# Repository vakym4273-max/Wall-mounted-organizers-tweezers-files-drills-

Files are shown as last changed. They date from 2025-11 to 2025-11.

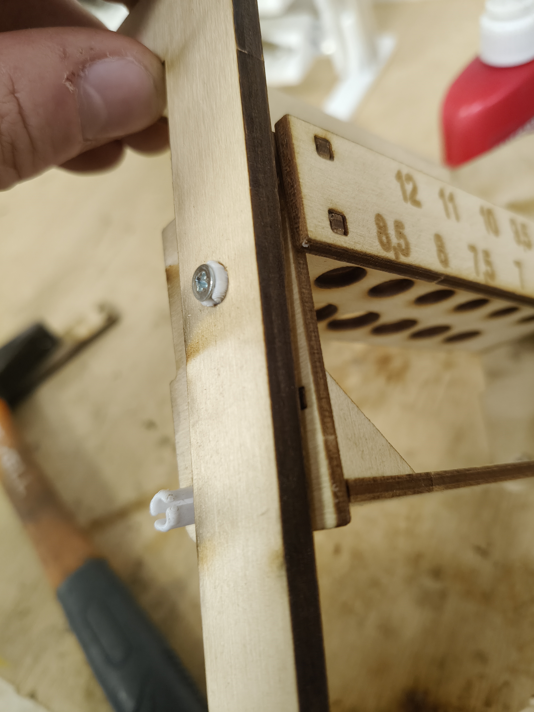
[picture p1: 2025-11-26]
Media/Photos/IMG20251120163726.jpg

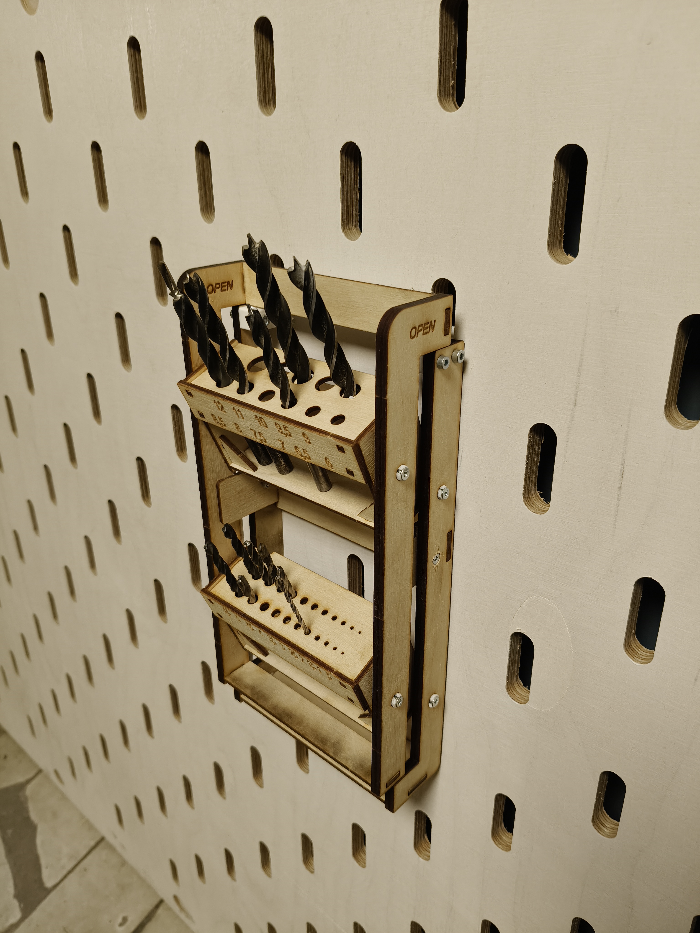
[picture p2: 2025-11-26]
Media/Photos/IMG20251120174527.jpg

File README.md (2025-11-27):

# 🛠️ Набор органайзеров для FabLab: свёрла, пинцеты, надфили

*Поворотно-выдвижной механизм для удобного доступа к инструментам*



[]()

## 🎯 О проекте

Набор из трёх настенных органайзеров, разработанных в рамках учебной практики "Практика цифрового производства" (FabLab). Особенность — инновационный поворотно-выдвижной механизм для органайзера свёрел.

### ✨ Особенности

**Органайзер для свёрел:**
- 🔄 **Поворотно-выдвижной механизм** — при раздвижении боковых стенок свёрла поворачиваются на 23° для удобного доступа
- 🎯 **Плотная фиксация** — каждый инструмент в отдельной ячейке  
- 🏗️ **Усиленная конструкция** — направляющие и винтовые соединения против люфта

**Органайзеры для пинцетов и надфилей:**
- 📏 **Эргономичное расположение** — быстрый доступ к часто используемым инструментам
- 🎪 **Компактность** — оптимальное использование пространства стены

## 🎥 Демонстрация

Работа механизма свёрел

## 📁 Структура проекта
**📁 CAD/**

│ ├── SolidWorks/ # Исходные файлы .SLDPRT, .SLDASM

│ └── STEP/ # Сборки в формате STEP

**📁 Production/**

│ ├── 3D_Print/ # STL и gcode файлы для 3D-печати

│ └── Laser_Cut/ # DXF файлы для лазерной резки

**📁 Documentation/**

│ ├── Технологический процесс сборки# Инструкция по сборке

**📁 Media/**

│ ├── Photos/ # Фотографии процесса и результата

│ ├── Videos/ # Видео сборки и работы

│ └── Gifs/ # Анимированные демонстрации

## 🛠 Технологии и материалы

### Оборудование
- **3D-принтер:** Prusa
- **Лазерный станок:** GCC Laser Pro
- **CAD:** SolidWorks

### Материалы
- **Фанера:** 3мм и 6мм (пазы рассчитаны на 2.85мм для плотной посадки)
- **PLA пластик** для 3D-печати
- **Крепёж:** Винты для усиления соединений
- **Клей:** ПВА для финальной фиксации

## 📋 Инструкция по сборке

### Подготовка деталей
1. **Лазерная резка:** Используйте файлы из папки `Laser_Cut/`
2. **3D-печать:** Напечатайте детали из папки `3D_Print/`
   - ⚠️ *Для мелких штифтов используйте высокое качество печати*

### Сборка органайзера свёрел
1. Соберите две внутрение секции из фанерных деталей
2. Соберите половину внешней рамы
3. Установите внутрение секции
4. Закройте второй половиной внешней части
5. Добавьте направляющие для уменьшения люфта, и винты по отверстиям штифтов
6. Проверьте работу механизма

### Монтаж на стену
1. Установите 3D-печатные крепления в пазы стены
2. Опустите органайзер для фиксации
3. Для надёжности можно зафиксировать клеем ПВА

## 🔧 Доработки и улучшения

В процессе тестирования были внесены следующие улучшения:
- ✅ **Направляющие** — добавлены для уменьшения люфта в механизме
- ✅ **Корректировка пазов** — размер уменьшен до 2.85мм для плотной посадки
- ✅ **Винтовое усиление** — штифты усилены винтами для прочности

## 👤 Автор

**Егор Смирнов** 
- Проект выполнен в рамках практики "Практика цифрового производства"
- Группа МТМО-25-3

---

*Проект разработан для лаборатории FabLab с целью оптимизации рабочего пространства*

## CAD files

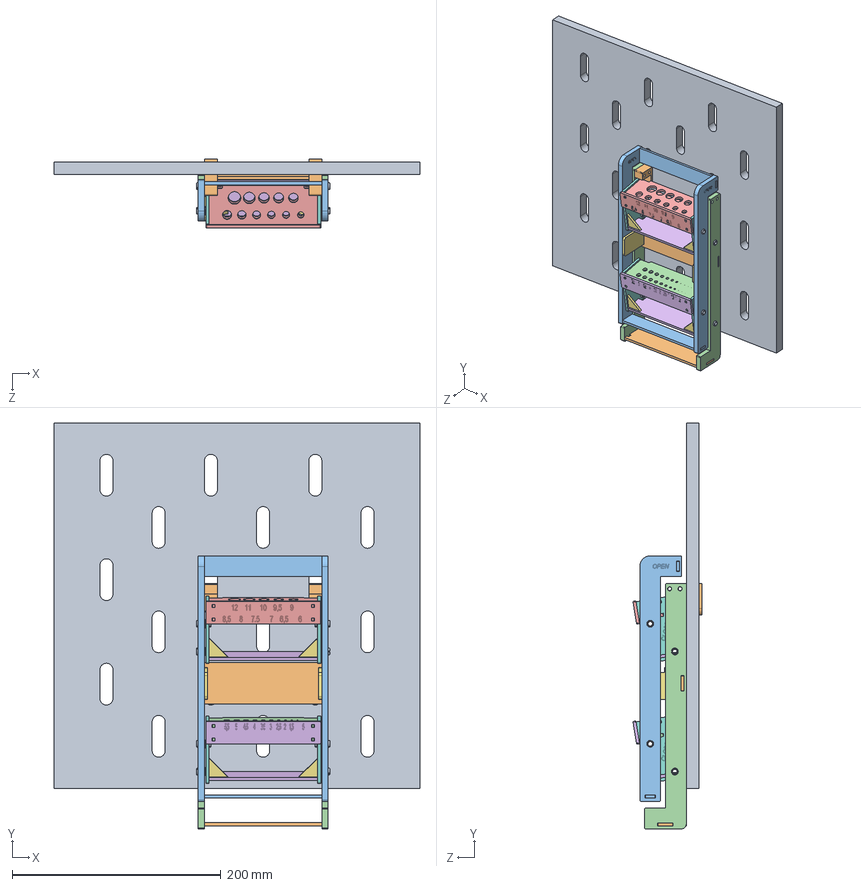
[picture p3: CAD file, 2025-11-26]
CAD/SolidWorks/Свёрла органайзер/0 Органайзер свёрла.SLDASM
350.0 x 388.8 x 66.3 mm
1 Стенка
2 Кронштейн свёрла x 2
4 Стенка подвижная свёрла x 2
3 Стенка основа свёрла x 2
7 Полка ячейки верхняя x 2
6 Полка ячейки нижняя x 2
10 Уголок свёрла x 4
5 Стенка ячейки x 4
9 штифт x 8
11 низ x 2
12 верх x 2
7.1 Полка ячейки верхняя x 2
13.1 маркировка свёрла верх
13.2 маркировка свёрла низ
14 направляюшая x 2

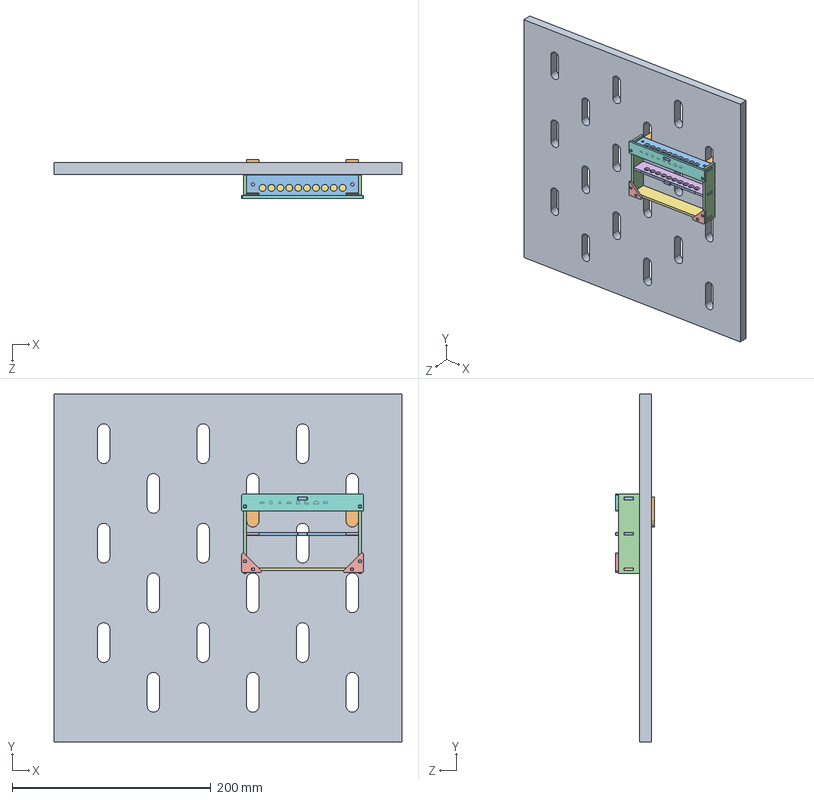
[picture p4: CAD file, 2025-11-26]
CAD/SolidWorks/Надфили органайзер/0 Органайзер надфили.SLDASM
350.0 x 350.0 x 39.5 mm
1 Стенка
2 Кронштейн надфили x 2
3 Полка верхняя надфили x 2
4 Стенка надфиди x 2
7 уголок x 2
5 Полка средняя надфили
6 Полка нижняя надфили
8 Маркировка

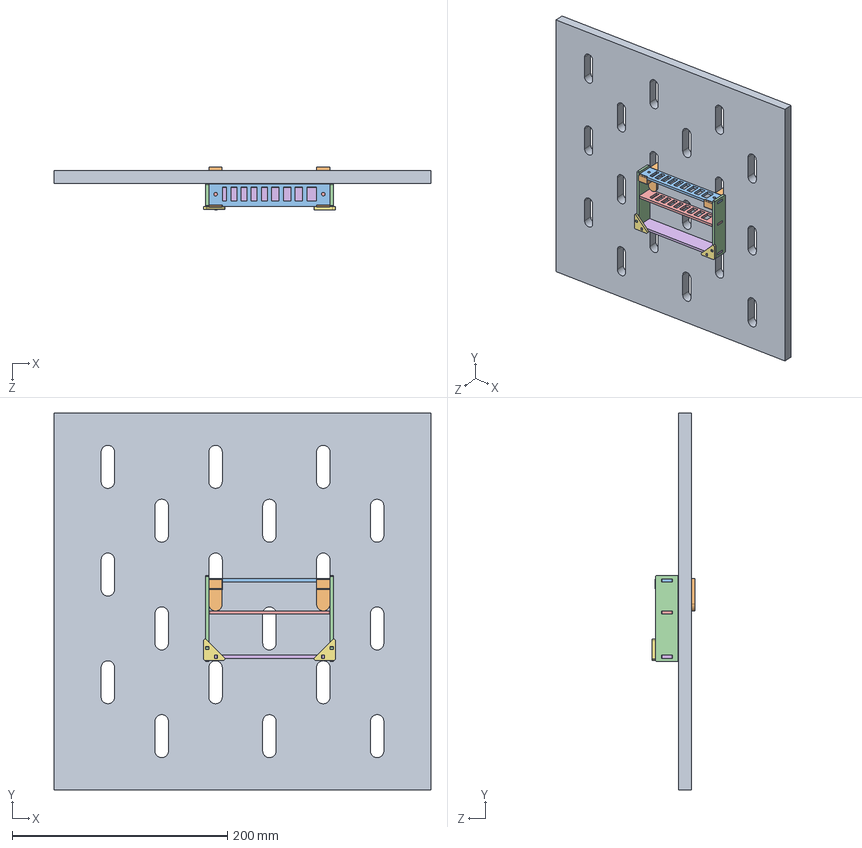
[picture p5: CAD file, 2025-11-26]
CAD/SolidWorks/Пинцеты органайзер/0 Органайзер пинцеты.SLDASM
350.0 x 350.0 x 39.8 mm
1 Стенка
2 Кронштейн Пинцеты x 2
3 Полка верхняя Пинцеты
4 Стенка пинцеты x 2
5 Полка средняя пинцеты
6 Полка нижняя пинцеты
7 уголок x 2

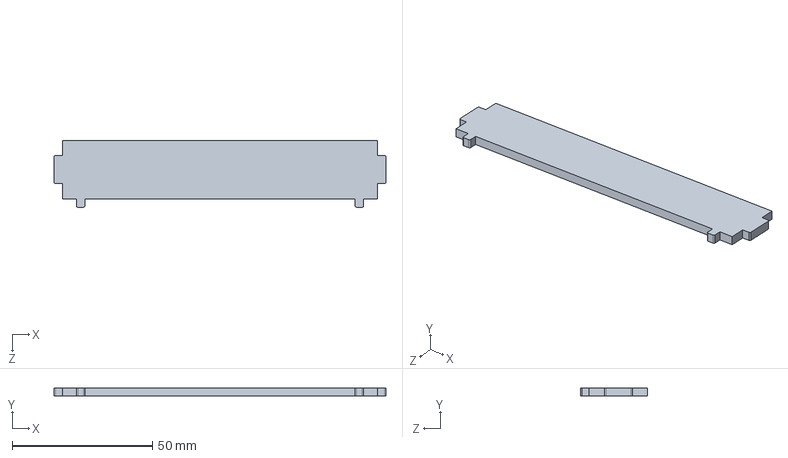
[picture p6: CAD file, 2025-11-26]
CAD/SolidWorks/Надфили органайзер/6 Полка нижняя надфили.SLDPRT
118.5 x 3.00 x 23.8 mm

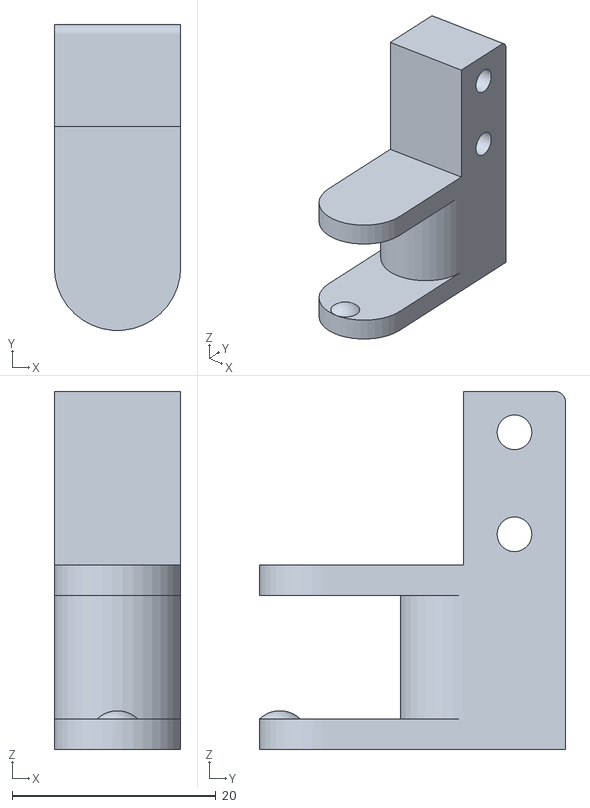
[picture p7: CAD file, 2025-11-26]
Production/3D_Print/2 Кронштейн свёрла.STL
12.4 x 30.0 x 35.1

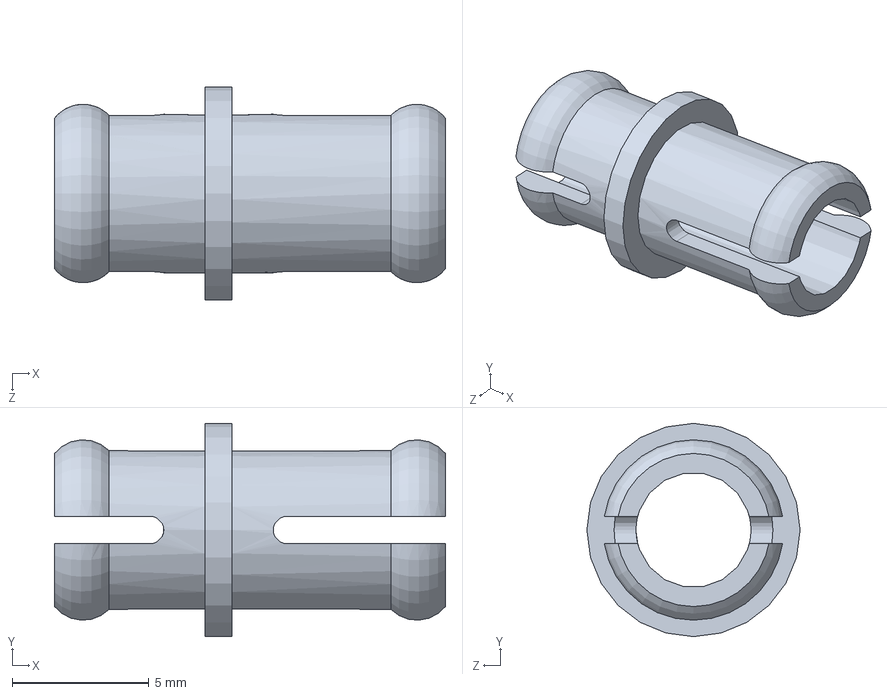
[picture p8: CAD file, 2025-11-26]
CAD/SolidWorks/Свёрла органайзер/9 штифт.SLDPRT
14.3 x 7.80 x 7.80 mm

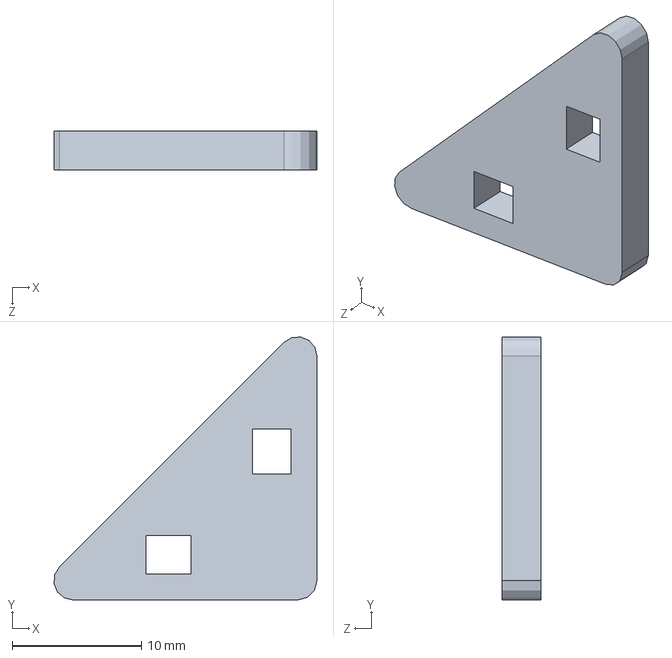
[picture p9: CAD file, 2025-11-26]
CAD/SolidWorks/Надфили органайзер/7 уголок.SLDPRT
20.4 x 20.4 x 3.00 mm

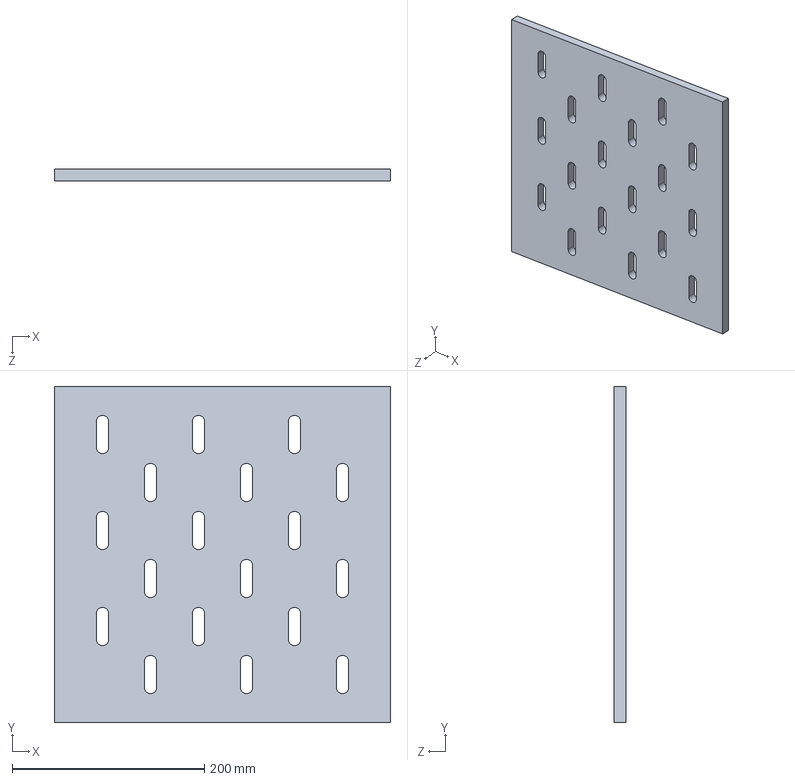
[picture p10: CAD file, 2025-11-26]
CAD/SolidWorks/Пинцеты органайзер/1 Стенка.SLDPRT
350.0 x 350.0 x 12.0 mm

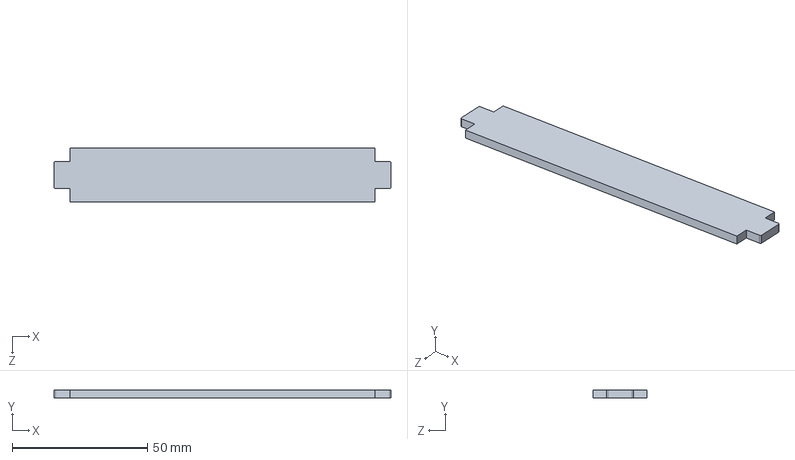
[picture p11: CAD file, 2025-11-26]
CAD/SolidWorks/Свёрла органайзер/12 верх.SLDPRT
124.5 x 3.00 x 20.0 mm

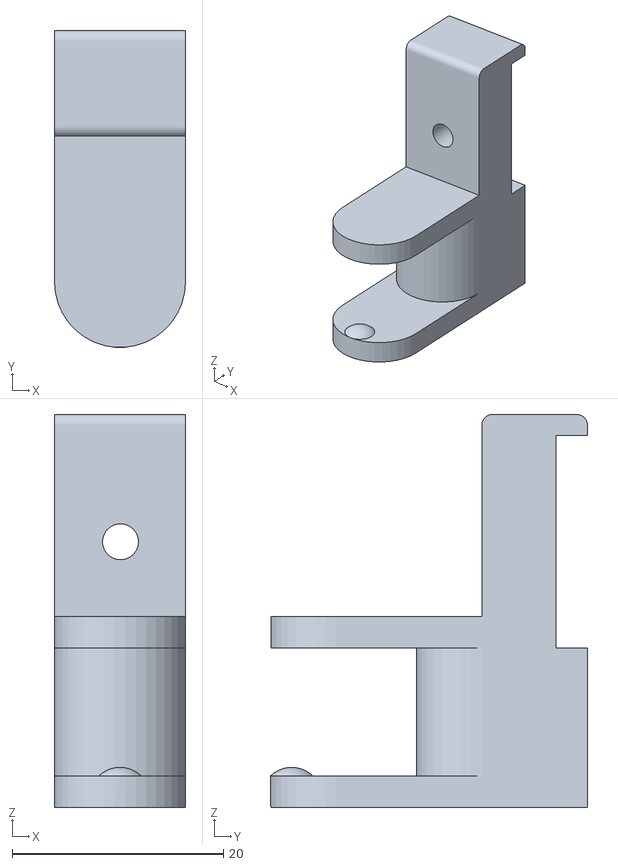
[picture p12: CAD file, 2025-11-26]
Production/3D_Print/2 Кронштейн Пинцеты.STL
12.4 x 30.0 x 37.2

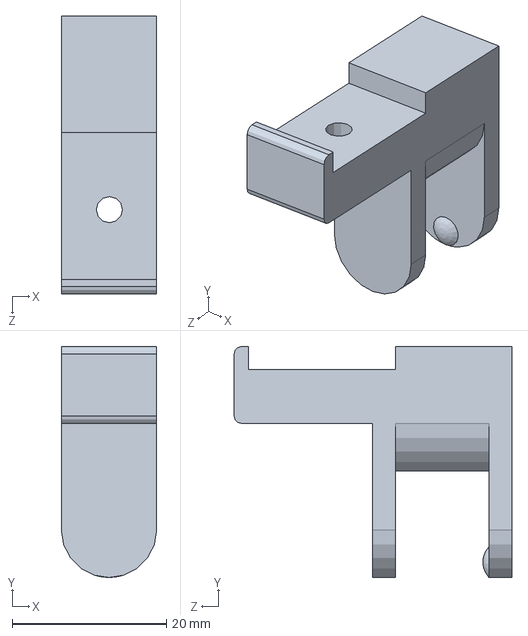
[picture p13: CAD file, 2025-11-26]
CAD/SolidWorks/Надфили органайзер/2 Кронштейн надфили.SLDPRT
12.4 x 30.0 x 36.1 mm

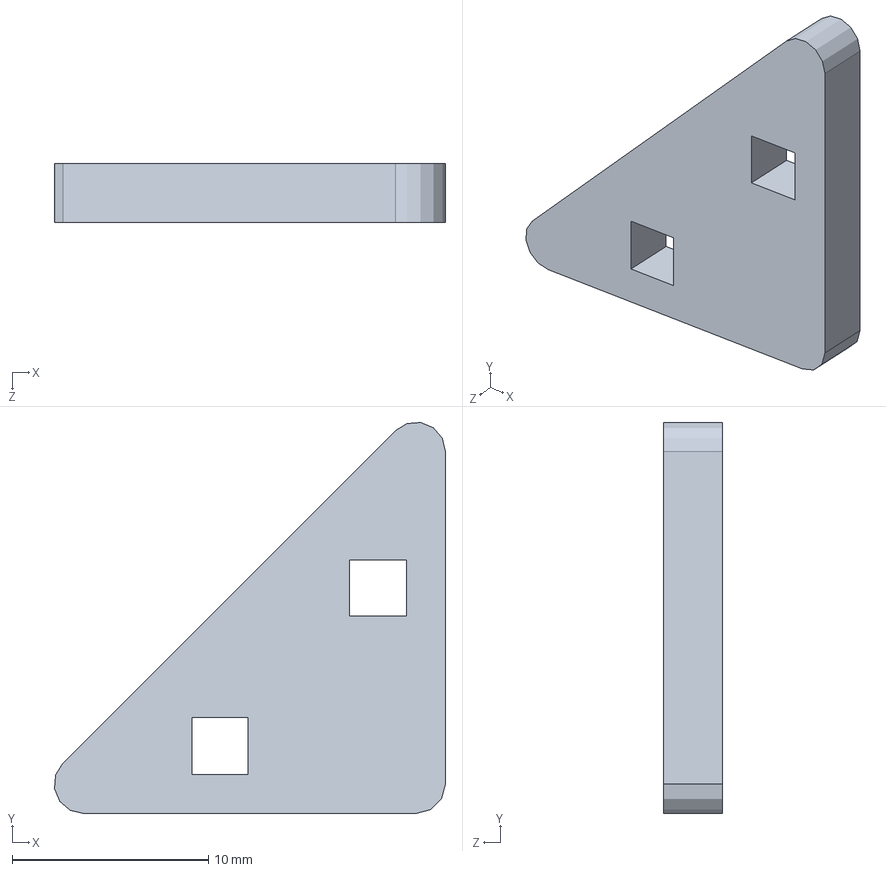
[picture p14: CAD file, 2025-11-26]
CAD/SolidWorks/Пинцеты органайзер/7 уголок.SLDPRT
19.9 x 19.9 x 3.00 mm

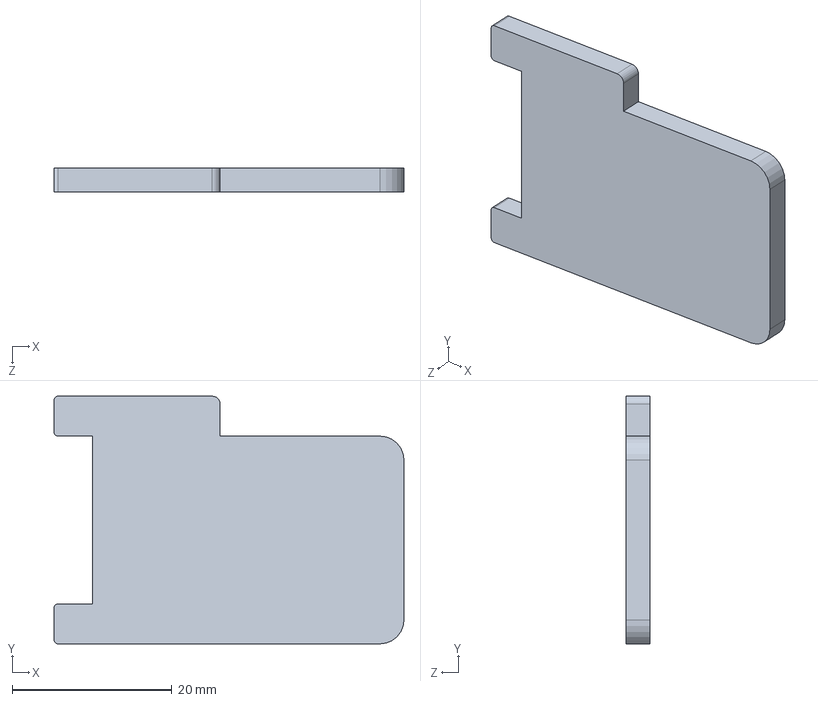
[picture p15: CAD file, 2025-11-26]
CAD/SolidWorks/Свёрла органайзер/14 направляюшая.SLDPRT
43.8 x 31.0 x 3.00 mm

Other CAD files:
CAD/SolidWorks/Пинцеты органайзер/6 Полка нижняя пинцеты.SLDPRT
CAD/STEP/0 Органайзер надфили.STEP
CAD/STEP/0 Органайзер пинцеты.STEP
Production/3D_Print/9 штифт.STL
Production/3D_Print/2 Кронштейн надфили.STL
CAD/SolidWorks/Надфили органайзер/1 Стенка.STEP
CAD/SolidWorks/Надфили органайзер/3 Полка верхняя надфили.SLDPRT
CAD/SolidWorks/Надфили органайзер/4 Стенка надфиди.SLDPRT
CAD/SolidWorks/Надфили органайзер/5 Полка средняя надфили.SLDPRT
CAD/SolidWorks/Надфили органайзер/8 Маркировка.SLDPRT
CAD/SolidWorks/Пинцеты органайзер/2 Кронштейн Пинцеты.SLDPRT
CAD/SolidWorks/Пинцеты органайзер/3 Полка верхняя Пинцеты.SLDPRT
CAD/SolidWorks/Пинцеты органайзер/4 Стенка пинцеты.SLDPRT
CAD/SolidWorks/Пинцеты органайзер/5 Полка средняя пинцеты.SLDPRT
CAD/SolidWorks/Свёрла органайзер/10 Уголок свёрла.SLDPRT
CAD/SolidWorks/Свёрла органайзер/11 низ.SLDPRT
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

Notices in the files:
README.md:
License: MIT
